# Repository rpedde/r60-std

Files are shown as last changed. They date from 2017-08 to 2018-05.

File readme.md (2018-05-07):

# r60 std #

This is just a simple poker 60% board as a base for testing
stuff.

It's a 16MHz Atmega32U4 running [quantum mechanical
keyboard](https://github.com/qmk/qmk_firmware) firmware.

It should fit in most (all?) 60% poker cases.

## CAD/CAM ##

I have cnc milled plates for this board using openscad/dxf files generated
from [this project](https://github.com/rpedde/platemaker).

I have cnc milled cases for this board using openscad/stl files generate
from [this project](https://github.com/rpedde/r60-case).

## Changelog ##

Rev 1 (Ordered through easyeda, verified working):

 - Initial rev

Rev 1.1 (Ordered through easyeda, verified working) [gerbers](https://storage.googleapis.com/rpedde-public-gerbers/r60-std-r1.1.zip):

 - Changed PTH holes on sides to edge slot cuts, for ease in mfg

Rev 1.2 (Not verified working):

 - Silkscreen fixes
 - Move speaker connector, allow for direct drive of 8 ohm speaker

Rev 2.0 (Not verified working) [gerbers](https://storage.googleapis.com/rpedde-public-gerbers/r60-std-r2.0.zip):

 - Use SMT diodes rather than through-hole
 - Align components to fit better on vortex cases (braces between rows)

Rev 2.1 (Not verified working) [gerbers](https://storage.googleapis.com/rpedde-public-gerbers/r60-std-r2.1.zip)

 - Switch SOD-323 footprint diodes to 0805

Rev 3.0 (ISO working, fitment problems with ANSI) [gerbers](https://storage.googleapis.com/rpedde-public-gerbers/r60-std-r3.0.zip):

 - Add option for stepped capslock/control
 - Add option for ISO as well as ANSI

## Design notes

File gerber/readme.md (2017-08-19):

# Gerber settings (kicad) #

## Layers ##

* F.Cu
* B.Cu
* B.Paste
* F.Paste
* B.SilkS
* F.SilkS
* B.Mask
* F.Mask
* Edge.Cuts

## Options ##

* Plot footprint values
* Plot footprint references
* Exclude PCB edge layer from other layers

Default line width: 0.1

## Gerber Options ##

Use Protel filename
Format: 4.6

# Drill settings (kicad) #

* Drill units: inches
* Zeros format: Suppress leading
* Drill Map: PostScript

* Drill File Options
  * Minimal header

* Drill origin: Absolute

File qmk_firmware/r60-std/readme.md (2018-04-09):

r60std keyboard firmware
========================

## Ugh

I didn't really want to carry around a fork of QMK, and I wanted the
firmware in this repo, but I did build this with QMK.

Get qmk from https://github.com/qmk/qmk_firwmare

rev1 boards:
------------

Check out rev 8a0997, link this directory as "r60std" in keyboards,
and then "make r60std/rev1:default" from the root of the qmk firmware
directory.  A r60std_rev1_default.hex should appear in the root of the qmk
directory.

rev3 boards:
------------

Check out rev 8a0997, link this directory as "r60std" in keyboards,
and then "make r60std/rev3:default_ansi" from the root of the qmk firmware
directory.  A r60std_rev1_default_ansi.hex should appear in the root of the qmk
directory.

The corresponding firmware for an ISO layout is "make r60std/rev3:default_iso".

## Layout

Default layout looks like this:

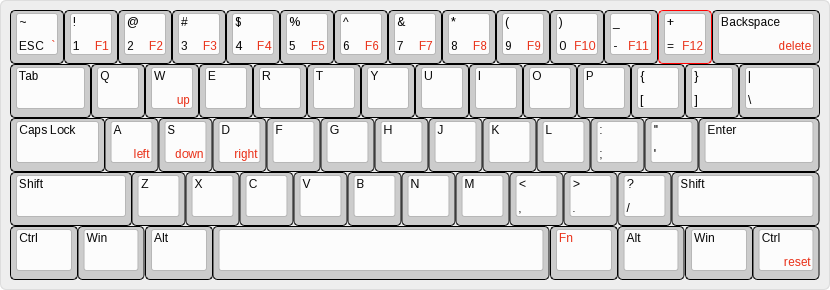
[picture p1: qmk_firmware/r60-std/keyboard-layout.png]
default keyboard layout


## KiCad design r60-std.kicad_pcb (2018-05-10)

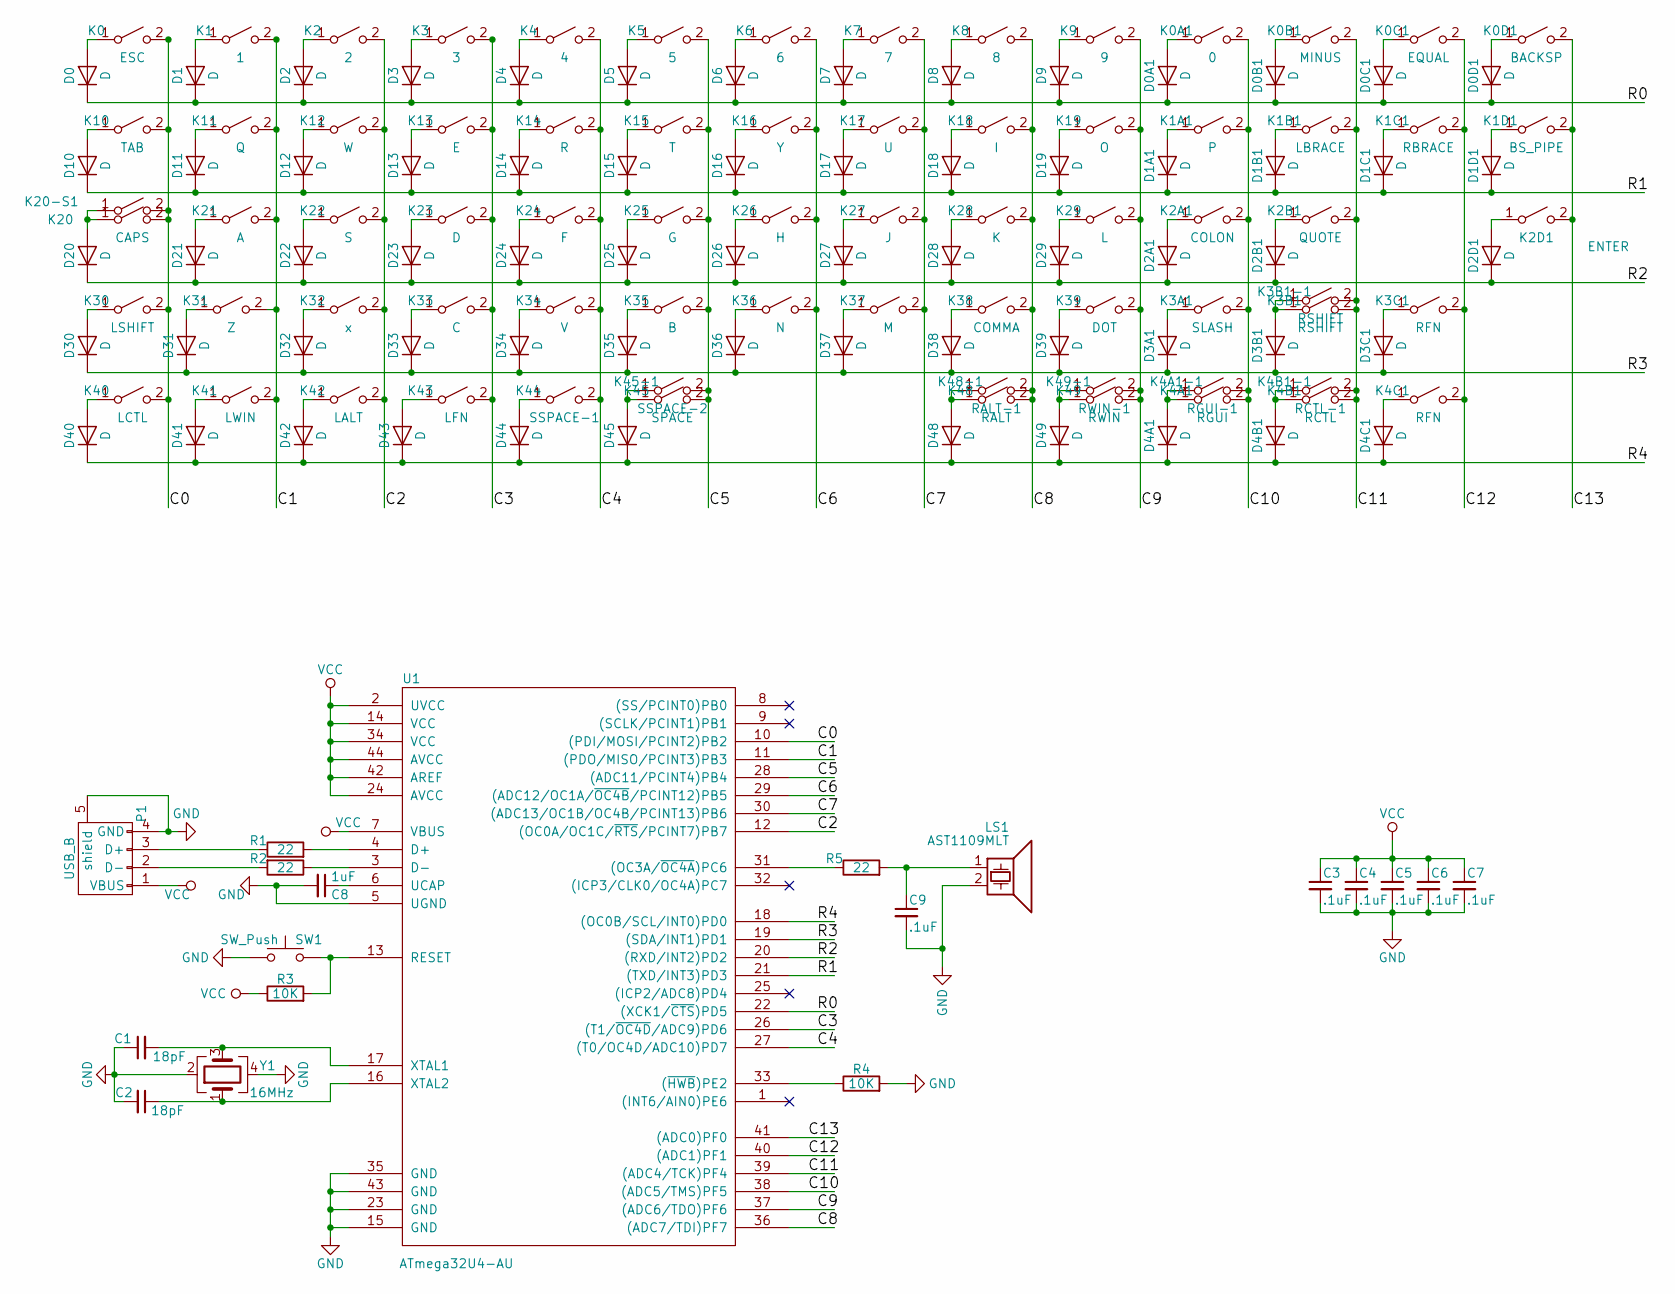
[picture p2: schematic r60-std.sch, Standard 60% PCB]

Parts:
C1, C2: 18pF; C_0603
C3, C4, C5, C6, C7: .1uF; C_0603
C8: 1uF; C_0603
C9: .1uF; C_0805
D0, D0A1, D0B1, D0C1, D0D1, D1, D1A1, D1B1, D1C1, D1D1, D2, D2A1, D2B1, D2D1, D3, D3A1, D3B1, D3C1, D4, D4A1, D4B1, D4C1, D5, D6, D7, D8, D9, D10, D11, D12, D13, D14, D15, D16, D17, D18, D19, D20, D21, D22, D23, D24, D25, D26, D27, D28, D29, D30, D31, D32, D33, D34, D35, D36, D37, D38, D39, D40, D41, D42, D43, D44, D45, D48, D49: D; D_0805
K0: ESC; CHERRY_PCB_100H
K0A1: 0; CHERRY_PCB_100H
K0B1: MINUS; CHERRY_PCB_100H
K0C1: EQUAL; CHERRY_PCB_100H
K0D1: BACKSP; CHERRY_PCB_200H_INVERTED
K1: 1; CHERRY_PCB_100H
K1A1: P; CHERRY_PCB_100H
K1B1: LBRACE; CHERRY_PCB_100H
K1C1: RBRACE; CHERRY_PCB_100H
K1D1: BS_PIPE; CHERRY_PCB_150H
K2: 2; CHERRY_PCB_100H
K2A1: COLON; CHERRY_PCB_100H
K2B1: QUOTE; CHERRY_PCB_100H
K2D1: ENTER; CHERRY_PCB_225H
K3: 3; CHERRY_PCB_100H
K3A1: SLASH; CHERRY_PCB_100H
K3B1: RSHIFT; CHERRY_PCB_275H
K3B1-1: RSHIFT; CHERRY_PCB_175H
K3C1, K4C1: RFN; CHERRY_PCB_100H
K4: 4; CHERRY_PCB_100H
K4A1: RGUI; CHERRY_PCB_125H
K4A1-1: RGUI-1; CHERRY_PCB_100H
K4B1: RCTL; CHERRY_PCB_125H
K4B1-1: RCTL-1; CHERRY_PCB_100H
K5: 5; CHERRY_PCB_100H
K6: 6; CHERRY_PCB_100H
K7: 7; CHERRY_PCB_100H
K8: 8; CHERRY_PCB_100H
K9: 9; CHERRY_PCB_100H
K10: TAB; CHERRY_PCB_150H
K11: Q; CHERRY_PCB_100H
K12: W; CHERRY_PCB_100H
K13: E; CHERRY_PCB_100H
K14: R; CHERRY_PCB_100H
K15: T; CHERRY_PCB_100H
K16: Y; CHERRY_PCB_100H
K17: U; CHERRY_PCB_100H
K18: I; CHERRY_PCB_100H
K19: O; CHERRY_PCB_100H
K20: CAPS; CHERRY_PCB_175H
K20-S1: CAPS; CHERRY_PCB_125H
K21: A; CHERRY_PCB_100H
K22: S; CHERRY_PCB_100H
K23: D; CHERRY_PCB_100H
K24: F; CHERRY_PCB_100H
K25: G; CHERRY_PCB_100H
K26: H; CHERRY_PCB_100H
K27: J; CHERRY_PCB_100H
K28: K; CHERRY_PCB_100H
K29: L; CHERRY_PCB_100H
K30: LSHIFT; CHERRY_PCB_225H
K31: Z; CHERRY_PCB_100H
K32: x; CHERRY_PCB_100H
K33: C; CHERRY_PCB_100H
K34: V; CHERRY_PCB_100H
K35: B; CHERRY_PCB_100H
K36: N; CHERRY_PCB_100H
K37: M; CHERRY_PCB_100H
K38: COMMA; CHERRY_PCB_100H
K39: DOT; CHERRY_PCB_100H
K40: LCTL; CHERRY_PCB_125H
K41: LWIN; CHERRY_PCB_125H
K42: LALT; CHERRY_PCB_125H
K43: LFN; CHERRY_PCB_125H
K44: SSPACE-1; CHERRY_PCB_225H
K45: SPACE; CHERRY_PCB_625H
K45-1: SSPACE-2; CHERRY_PCB_275H
K48: RALT; CHERRY_PCB_125H
K48-1: RALT-1; CHERRY_PCB_100H
K49: RWIN; CHERRY_PCB_125H
K49-1: RWIN-1; CHERRY_PCB_100H
LS1: AST1109MLT; AST1109ML-SMT
P1: USB_B; USB_Mini-B
R1, R2, R5: 22; RC_0805
R3: 10K; RC_0805
R4: 10K; R_0603
SW1: SW_Push; SW_SPST_TL3342
U1: ATmega32U4-AU; QFN-44-1EP_7x7mm_Pitch0.5mm
Y1: 16MHz; Crystal_SMD_3225-4pin_3.2x2.5mm

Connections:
/C0: K0.2 (B), K10.2 (B), K20.2 (B), K20-S1.2 (B), K30.2 (B), K40.2 (B), U1.10 ((PDI/MOSI/PCINT2)PB2)
/C1: K1.2 (B), K11.2 (B), K21.2 (B), K31.2 (B), K41.2 (B), U1.11 ((PDO/MISO/PCINT3)PB3)
/C2: K2.2 (B), K12.2 (B), K22.2 (B), K32.2 (B), K42.2 (B), U1.12 ((OC0A/OC1C/~RTS~/PCINT7)PB7)
/C3: K3.2 (B), K13.2 (B), K23.2 (B), K33.2 (B), K43.2 (B), U1.26 ((T1/~OC4D~/ADC9)PD6)
/C4: K4.2 (B), K14.2 (B), K24.2 (B), K34.2 (B), K44.2 (B), U1.27 ((T0/OC4D/ADC10)PD7)
/C5: K5.2 (B), K15.2 (B), K25.2 (B), K35.2 (B), K45.2 (B), K45-1.2 (B), U1.28 ((ADC11/PCINT4)PB4)
/C6: K6.2 (B), K16.2 (B), K26.2 (B), K36.2 (B), U1.29 ((ADC12/OC1A/~OC4B~/PCINT12)PB5)
/C7: K7.2 (B), K17.2 (B), K27.2 (B), K37.2 (B), U1.30 ((ADC13/OC1B/OC4B/PCINT13)PB6)
/C8: K8.2 (B), K18.2 (B), K28.2 (B), K38.2 (B), K48.2 (B), K48-1.2 (B), U1.36 ((ADC7/TDI)PF7)
/C9: K9.2 (B), K19.2 (B), K29.2 (B), K39.2 (B), K49.2 (B), K49-1.2 (B), U1.37 ((ADC6/TDO)PF6)
/C10: K0A1.2 (B), K1A1.2 (B), K2A1.2 (B), K3A1.2 (B), K4A1.2 (B), K4A1-1.2 (B), U1.38 ((ADC5/TMS)PF5)
/C11: K0B1.2 (B), K1B1.2 (B), K2B1.2 (B), K3B1.2 (B), K3B1-1.2 (B), K4B1.2 (B), K4B1-1.2 (B), U1.39 ((ADC4/TCK)PF4)
/C12: K0C1.2 (B), K1C1.2 (B), K3C1.2 (B), K4C1.2 (B), U1.40 ((ADC1)PF1)
/C13: K0D1.2 (B), K1D1.2 (B), K2D1.2 (B), U1.41 ((ADC0)PF0)
/R0: D0.1 (K), D0A1.1 (K), D0B1.1 (K), D0C1.1 (K), D0D1.1 (K), D1.1 (K), D2.1 (K), D3.1 (K), D4.1 (K), D5.1 (K), D6.1 (K), D7.1 (K), D8.1 (K), D9.1 (K), U1.22 ((XCK1/~CTS~)PD5)
/R1: D1A1.1 (K), D1B1.1 (K), D1C1.1 (K), D1D1.1 (K), D10.1 (K), D11.1 (K), D12.1 (K), D13.1 (K), D14.1 (K), D15.1 (K), D16.1 (K), D17.1 (K), D18.1 (K), D19.1 (K), U1.21 ((TXD/INT3)PD3)
/R2: D2A1.1 (K), D2B1.1 (K), D2D1.1 (K), D20.1 (K), D21.1 (K), D22.1 (K), D23.1 (K), D24.1 (K), D25.1 (K), D26.1 (K), D27.1 (K), D28.1 (K), D29.1 (K), U1.20 ((RXD/INT2)PD2)
/R3: D3A1.1 (K), D3B1.1 (K), D3C1.1 (K), D30.1 (K), D31.1 (K), D32.1 (K), D33.1 (K), D34.1 (K), D35.1 (K), D36.1 (K), D37.1 (K), D38.1 (K), D39.1 (K), U1.19 ((SDA/INT1)PD1)
/R4: D4A1.1 (K), D4B1.1 (K), D4C1.1 (K), D40.1 (K), D41.1 (K), D42.1 (K), D43.1 (K), D44.1 (K), D45.1 (K), D48.1 (K), D49.1 (K), U1.18 ((OC0B/SCL/INT0)PD0)
GND: C1.1, C2.2, C3.2, C4.2, C5.2, C6.2, C7.2, C8.2, C9.2, LS1.2, P1.4 (GND), P1.5 (shield), R4.2, SW1.1, U1.5 (UGND), U1.15 (GND), U1.23 (GND), U1.35 (GND), U1.43 (GND), U1.45, Y1.2, Y1.4
unnamed: C1.2, U1.17 (XTAL1), Y1.3
unnamed: C2.1, U1.16 (XTAL2), Y1.1
unnamed: C8.1, U1.6 (UCAP)
unnamed: C9.1, LS1.1, R5.2
unnamed: D0.2 (A), K0.1 (A)
unnamed: D0A1.2 (A), K0A1.1 (A)
unnamed: D0B1.2 (A), K0B1.1 (A)
unnamed: D0C1.2 (A), K0C1.1 (A)
unnamed: D0D1.2 (A), K0D1.1 (A)
unnamed: D1.2 (A), K1.1 (A)
unnamed: D1A1.2 (A), K1A1.1 (A)
unnamed: D1B1.2 (A), K1B1.1 (A)
unnamed: D1C1.2 (A), K1C1.1 (A)
unnamed: D1D1.2 (A), K1D1.1 (A)
unnamed: D2.2 (A), K2.1 (A)
unnamed: D2A1.2 (A), K2A1.1 (A)
unnamed: D2B1.2 (A), K2B1.1 (A)
unnamed: D2D1.2 (A), K2D1.1 (A)
unnamed: D3.2 (A), K3.1 (A)
unnamed: D3A1.2 (A), K3A1.1 (A)
unnamed: D3B1.2 (A), K3B1.1 (A), K3B1-1.1 (A)
unnamed: D3C1.2 (A), K3C1.1 (A)
unnamed: D4.2 (A), K4.1 (A)
unnamed: D4A1.2 (A), K4A1.1 (A), K4A1-1.1 (A)
unnamed: D4B1.2 (A), K4B1.1 (A), K4B1-1.1 (A)
unnamed: D4C1.2 (A), K4C1.1 (A)
unnamed: D5.2 (A), K5.1 (A)
unnamed: D6.2 (A), K6.1 (A)
unnamed: D7.2 (A), K7.1 (A)
unnamed: D8.2 (A), K8.1 (A)
unnamed: D9.2 (A), K9.1 (A)
unnamed: D10.2 (A), K10.1 (A)
unnamed: D11.2 (A), K11.1 (A)
unnamed: D12.2 (A), K12.1 (A)
unnamed: D13.2 (A), K13.1 (A)
unnamed: D14.2 (A), K14.1 (A)
unnamed: D15.2 (A), K15.1 (A)
unnamed: D16.2 (A), K16.1 (A)
unnamed: D17.2 (A), K17.1 (A)
unnamed: D18.2 (A), K18.1 (A)
unnamed: D19.2 (A), K19.1 (A)
unnamed: D20.2 (A), K20.1 (A), K20-S1.1 (A)
unnamed: D21.2 (A), K21.1 (A)
unnamed: D22.2 (A), K22.1 (A)
unnamed: D23.2 (A), K23.1 (A)
unnamed: D24.2 (A), K24.1 (A)
unnamed: D25.2 (A), K25.1 (A)
unnamed: D26.2 (A), K26.1 (A)
unnamed: D27.2 (A), K27.1 (A)
unnamed: D28.2 (A), K28.1 (A)
unnamed: D29.2 (A), K29.1 (A)
unnamed: D30.2 (A), K30.1 (A)
unnamed: D31.2 (A), K31.1 (A)
unnamed: D32.2 (A), K32.1 (A)
unnamed: D33.2 (A), K33.1 (A)
unnamed: D34.2 (A), K34.1 (A)
unnamed: D35.2 (A), K35.1 (A)
unnamed: D36.2 (A), K36.1 (A)
unnamed: D37.2 (A), K37.1 (A)
unnamed: D38.2 (A), K38.1 (A)
unnamed: D39.2 (A), K39.1 (A)
unnamed: D40.2 (A), K40.1 (A)
unnamed: D41.2 (A), K41.1 (A)
unnamed: D42.2 (A), K42.1 (A)
unnamed: D43.2 (A), K43.1 (A)
unnamed: D44.2 (A), K44.1 (A)
unnamed: D45.2 (A), K45.1 (A), K45-1.1 (A)
unnamed: D48.2 (A), K48.1 (A), K48-1.1 (A)
unnamed: D49.2 (A), K49.1 (A), K49-1.1 (A)
unnamed: P1.2 (D-), R2.2
unnamed: P1.3 (D+), R1.1
unnamed: R1.2, U1.4 (D+)
unnamed: R2.1, U1.3 (D-)
unnamed: R3.2, SW1.2, U1.13 (RESET)
unnamed: R4.1, U1.33 ((~HWB~)PE2)
unnamed: R5.1, U1.31 ((OC3A/~OC4A~)PC6)
VCC: C3.1, C4.1, C5.1, C6.1, C7.1, P1.1 (VBUS), R3.1, U1.2 (UVCC), U1.7 (VBUS), U1.14 (VCC), U1.24 (AVCC), U1.34 (VCC), U1.42 (AREF), U1.44 (AVCC)

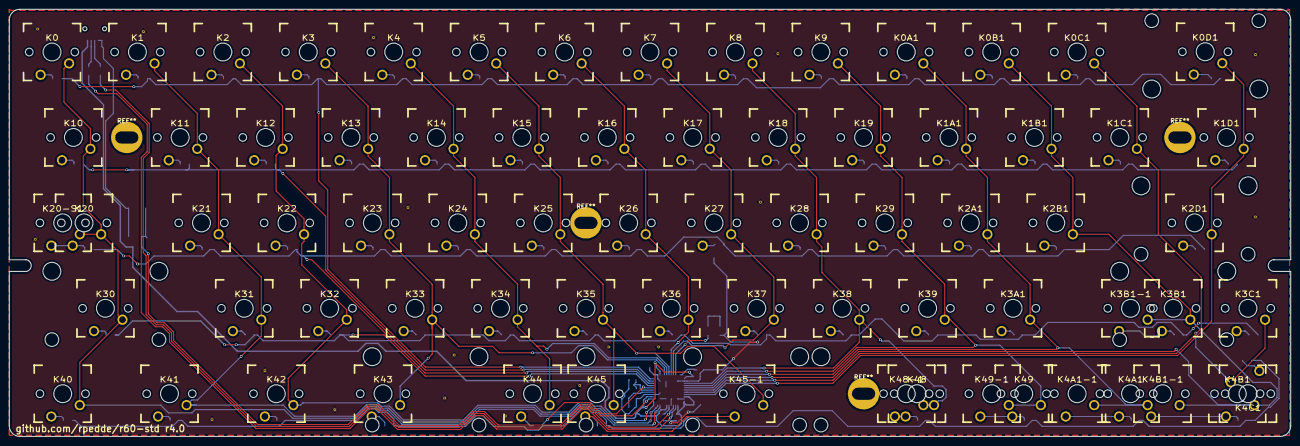
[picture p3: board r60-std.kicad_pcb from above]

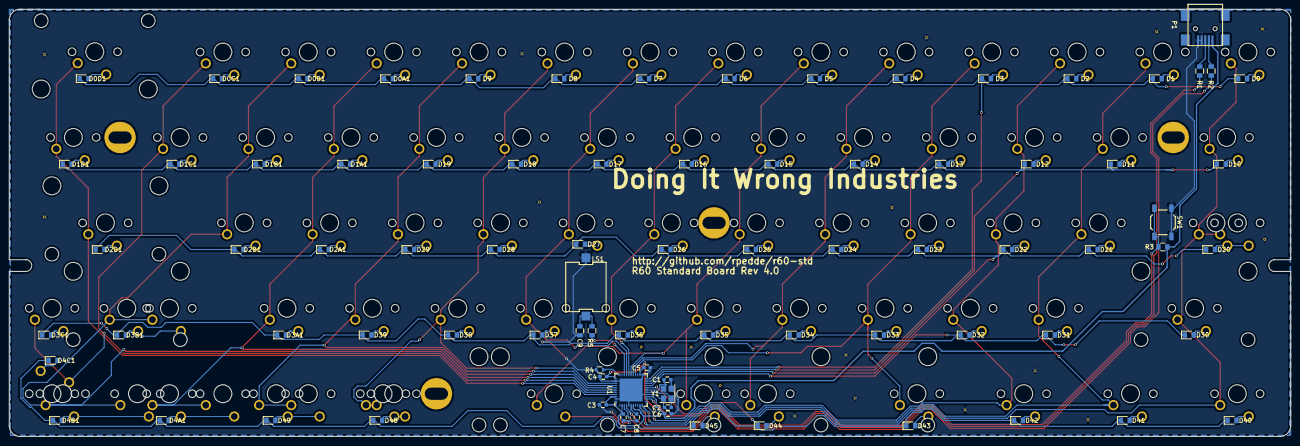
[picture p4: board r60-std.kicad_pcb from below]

Board: 2 copper layers, 285.8 x 95.3 mm, 156 parts (84 on the bottom side), 97 nets.

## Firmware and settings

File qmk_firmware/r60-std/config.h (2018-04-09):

/*
Copyright 2017 Ron Pedde <ron@pedde.com>

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
You should have received a copy of the GNU General Public License
along with this program.  If not, see <http://www.gnu.org/licenses/>.
*/

#ifndef CONFIG_H
#define CONFIG_H

#include "config_common.h"

/* USB Device descriptor parameter */
#define VENDOR_ID       0xFEED
#define PRODUCT_ID      0x6060
#define MANUFACTURER    Ron Pedde
#define PRODUCT         r60std
#define DESCRIPTION     A simple 60% keyboard

/* key matrix size */
#define MATRIX_ROWS 5
#define MATRIX_COLS 14

/*
 * Keyboard Matrix Assignments
 *
 * Change this to how you wired your keyboard
 * COLS: AVR pins used for columns, left to right
 * ROWS: AVR pins used for rows, top to bottom
 * DIODE_DIRECTION: COL2ROW = COL = Anode (+), ROW = Cathode (-, marked on diode)
 *                  ROW2COL = ROW = Anode (+), COL = Cathode (-, marked on diode)
 *
*/
#define MATRIX_ROW_PINS { D5, D3, D2, D1, D0 }
#define MATRIX_COL_PINS { B2, B3, B7, D6, D7, B4, B5, B6, F7, F6, F5, F4, F1, F0 }
#define UNUSED_PINS

/* COL2ROW, ROW2COL, or CUSTOM_MATRIX */
#define DIODE_DIRECTION COL2ROW

//#define BACKLIGHT_PIN B6
// #define BACKLIGHT_BREATHING
//#define BACKLIGHT_LEVELS 4


/* Debounce reduces chatter (unintended double-presses) - set 0 if debouncing is not needed */
#define DEBOUNCING_DELAY 5

/* define if matrix has ghost (lacks anti-ghosting diodes) */
//#define MATRIX_HAS_GHOST

/* number of backlight levels */

/* Mechanical locking support. Use KC_LCAP, KC_LNUM or KC_LSCR instead in keymap */
#define LOCKING_SUPPORT_ENABLE
/* Locking resynchronize hack */
#define LOCKING_RESYNC_ENABLE

/* #define AUDIO_VOICES */

/*
 * Force NKRO
 *
 * Force NKRO (nKey Rollover) to be enabled by default, regardless of the saved
 * state in the bootmagic EEPROM settings. (Note that NKRO must be enabled in the
 * makefile for this to work.)
 *
 * If forced on, NKRO can be disabled via magic key (default = LShift+RShift+N)
 * until the next keyboard reset.
 *
 * NKRO may prevent your keystrokes from being detected in the BIOS, but it is
 * fully operational during normal computer usage.
 *
 * For a less heavy-handed approach, enable NKRO via magic key (LShift+RShift+N)
 * or via bootmagic (hold SPACE+N while plugging in the keyboard). Once set by
 * bootmagic, NKRO mode will always be enabled until it is toggled again during a
 * power-up.
 *
 */
//#define FORCE_NKRO

/*
 * Magic Key Options
 *
 * Magic keys are hotkey commands that allow control over firmware functions of
 * the keyboard. They are best used in combination with the HID Listen program,
 * found here: https://www.pjrc.com/teensy/hid_listen.html
 *
 * The options below allow the magic key functionality to be changed. This is
 * useful if your keyboard/keypad is missing keys and you want magic key support.
 *
 */

/* key combination for magic key command */
#define IS_COMMAND() ( \
    keyboard_report->mods == (MOD_BIT(KC_LSHIFT) | MOD_BIT(KC_RSHIFT)) \
)

/* control how magic key switches layers */
//#define MAGIC_KEY_SWITCH_LAYER_WITH_FKEYS  true
//#define MAGIC_KEY_SWITCH_LAYER_WITH_NKEYS  true
//#define MAGIC_KEY_SWITCH_LAYER_WITH_CUSTOM false

/* override magic key keymap */
//#define MAGIC_KEY_SWITCH_LAYER_WITH_FKEYS
//#define MAGIC_KEY_SWITCH_LAYER_WITH_NKEYS
//#define MAGIC_KEY_SWITCH_LAYER_WITH_CUSTOM
//#define MAGIC_KEY_HELP1          H
//#define MAGIC_KEY_HELP2          SLASH
//#define MAGIC_KEY_DEBUG          D
//#define MAGIC_KEY_DEBUG_MATRIX   X
//#define MAGIC_KEY_DEBUG_KBD      K
//#define MAGIC_KEY_DEBUG_MOUSE    M
//#define MAGIC_KEY_VERSION        V
//#define MAGIC_KEY_STATUS         S
//#define MAGIC_KEY_CONSOLE        C
//#define MAGIC_KEY_LAYER0_ALT1    ESC
//#define MAGIC_KEY_LAYER0_ALT2    GRAVE
//#define MAGIC_KEY_LAYER0         0
//#define MAGIC_KEY_LAYER1         1
//#define MAGIC_KEY_LAYER2         2
//#define MAGIC_KEY_LAYER3         3
//#define MAGIC_KEY_LAYER4         4
//#define MAGIC_KEY_LAYER5         5
//#define MAGIC_KEY_LAYER6         6
//#define MAGIC_KEY_LAYER7         7
//#define MAGIC_KEY_LAYER8         8
//#define MAGIC_KEY_LAYER9         9
//#define MAGIC_KEY_BOOTLOADER     PAUSE
//#define MAGIC_KEY_LOCK           CAPS
//#define MAGIC_KEY_EEPROM         E
//#define MAGIC_KEY_NKRO           N
//#define MAGIC_KEY_SLEEP_LED      Z

/*
 * Feature disable options
 *  These options are also useful to firmware size reduction.
 */

/* disable debug print */
//#define NO_DEBUG

/* disable print */
//#define NO_PRINT

/* disable action features */
//#define NO_ACTION_LAYER
//#define NO_ACTION_TAPPING
//#define NO_ACTION_ONESHOT
//#define NO_ACTION_MACRO
//#define NO_ACTION_FUNCTION

/*
 * MIDI options
 */

/* Prevent use of disabled MIDI features in the keymap */
//#define MIDI_ENABLE_STRICT 1

/* enable basic MIDI features:
   - MIDI notes can be sent when in Music mode is on
*/
//#define MIDI_BASIC
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

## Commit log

2017-08-19 Initial version
    [r60-std-B.Cu.gbl, r60-std-B.Mask.gbs, r60-std-B.Paste.gbp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]
2017-08-19 Change cut edge holes to slot cuts
    [r60-std-B.Cu.gbl, r60-std-B.Mask.gbs, r60-std-B.Paste.gbp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]
2017-08-23 Fix silkscreen, move speaker connector, add speaker hardware
    [r60-std.kicad_pcb, r60-std.sch]
2017-10-04 start on r2.0 board
    [r60-std.kicad_pcb, r60-std.sch]
2017-10-05 missing some ground pads
    [r60-std.kicad_pcb]
2017-10-07 generate r2.0 gerbers
    [r60-std-B.Cu.gbl, r60-std-B.Mask.gbs, r60-std-B.Paste.gbp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]
2018-01-06 switch to 0805 diodes
    [r60-std.kicad_pcb, r60-std.sch]
2018-01-24 Expand out 0805 pads on both r and d
    re-route some traces as a consequence.
    [r60-std-B.Cu.gbl, r60-std-B.Mask.gbs, r60-std-B.Paste.gbp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]
2018-03-26 add ISO and stepped capslock support
    [r60-std-B.Cu.gbl, r60-std-B.Mask.gbs, r60-std-B.Paste.gbp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]
2018-04-09 update firmware for rev3 boards
2018-05-07 First pass at r4 design
    Remove ISO layouts, keep stepped capslock/ctrl. Allow for
    either 6.25u space or 1.25/2.25/2.75 split space. Move to
    0603 footprints near atmega to handle smaller space due to
    split spacebar. Switch atmega from -AU in 44 TQFP to -MU
    part in 44 QFN, again to deal with less room due to split
    spacebar.
    [r60-std.kicad_pcb, r60-std.sch]
2018-05-10 add option for split right shift
    [r60-std-B.Cu.gbl, r60-std-B.Mask.gbs, r60-std-B.Paste.gbp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]
2018-05-21 default 60% firmware for rev4 boards

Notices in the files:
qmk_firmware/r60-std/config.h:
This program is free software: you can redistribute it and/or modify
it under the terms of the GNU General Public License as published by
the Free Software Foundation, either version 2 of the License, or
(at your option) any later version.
